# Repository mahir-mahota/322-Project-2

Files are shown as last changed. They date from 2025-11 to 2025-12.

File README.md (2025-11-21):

# 322-Project-2

1. Measure distances on the shaft and the forces from the gear
2. Find FrI and FrII (Fae is given) using moment equations
3. Find FaI and FaII, assuming axial load is not negligible
4. Find the effective loads PI and PII, P0I and P0II
5. Compute required C and C0 from L10 and fs
6. Compare with bearing C and C0 for feasability

For C:

1. The minimum shaft diameter is 54.6mm, and the maximum is 66mm - 55mm and 65mm are too close to the bounds
2. The housing width is 120mm so the bearing out diameter has to be smaller |red|
3. Without reducing housing thickness, the max bearing width T must be <30mm and we're contraining to >25mm

For D:

1. 70mm inner diameter is the smallest bearing that leads to an outer diameter of >= 150mm
2. The diameter of the pinion is 150mm so outer diameter of bearing has to be greater |red|

55-75 (55 is too small)
65-80 (80 has a 170 OD which is cutting it close)
65-85 (1mm step on shaft on either side)

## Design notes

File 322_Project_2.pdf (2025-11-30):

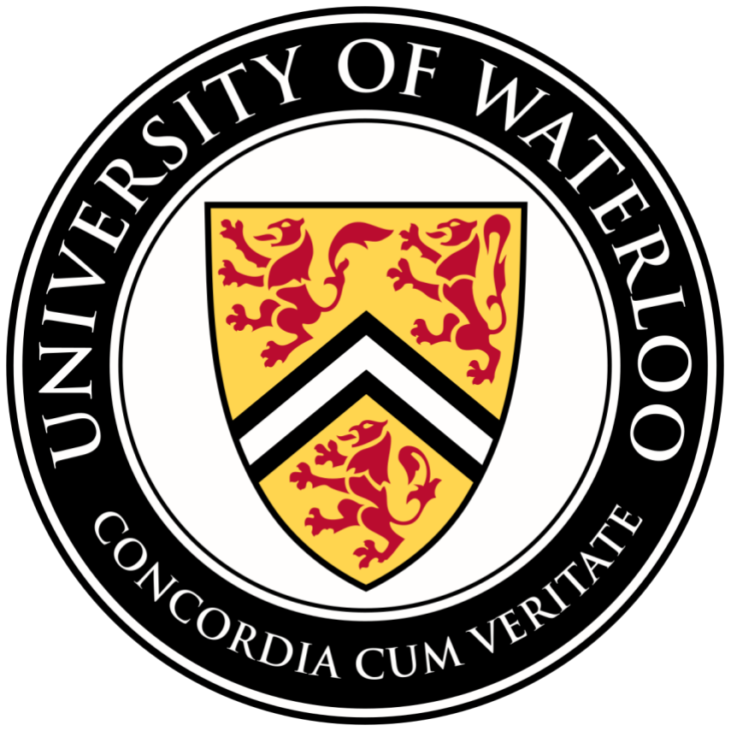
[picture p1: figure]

# MTE 322 PROJECT 2

# Mahir Mahota – 20991134 Vinesh Vivekanand – 21000784

## 28th October, 2025

### Motor selection

The input speed of the thrust motor on the pinion is ηP1 = 1,720rpm. Calculating the power required of the motor is:

Pout = 14,914N ∗ 10

m
s

= 149,140

Nm
s

= 149,140W = 149.14kW

Since there is no loss in power throughout the system, the output power is the same as the input power and countershaft power throughout the entire system, therefore:

Pout = Pcountersℎaft = Pin = 149.14kW

149.14kW ∗ 1.341 = 199.99674 ≈ 200ℎp
Therefore, selecting a motor with 200hp provides a suitable rating for this application. At the given power, a speed of 1800 rpm was selected based on the required 1,720 rpm.
Out of the options given, the cheapest Marathon E631A (https://www.emotorsdirect.ca/item/marathon-e631a) AC induction motor was chosen.

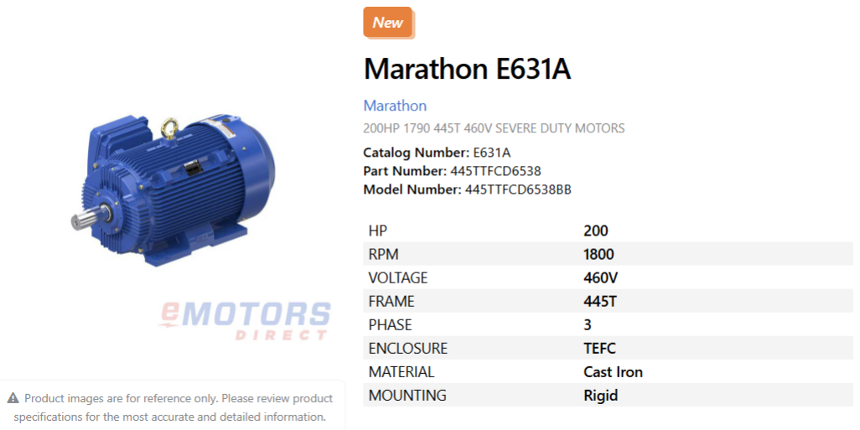
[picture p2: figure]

Figure 1 Selected motor for input shaft

### Bearing Selection

From Project 1:
WrG1 = WxP1 = 2.28 kN

WxG1 = WrP1 = 3.65 kN

WtG1 = WtP1 = 11.8kN
Below is the 3D FBD for the input shaft which is split into the x-z and y-z planes for two 2D FBDs:

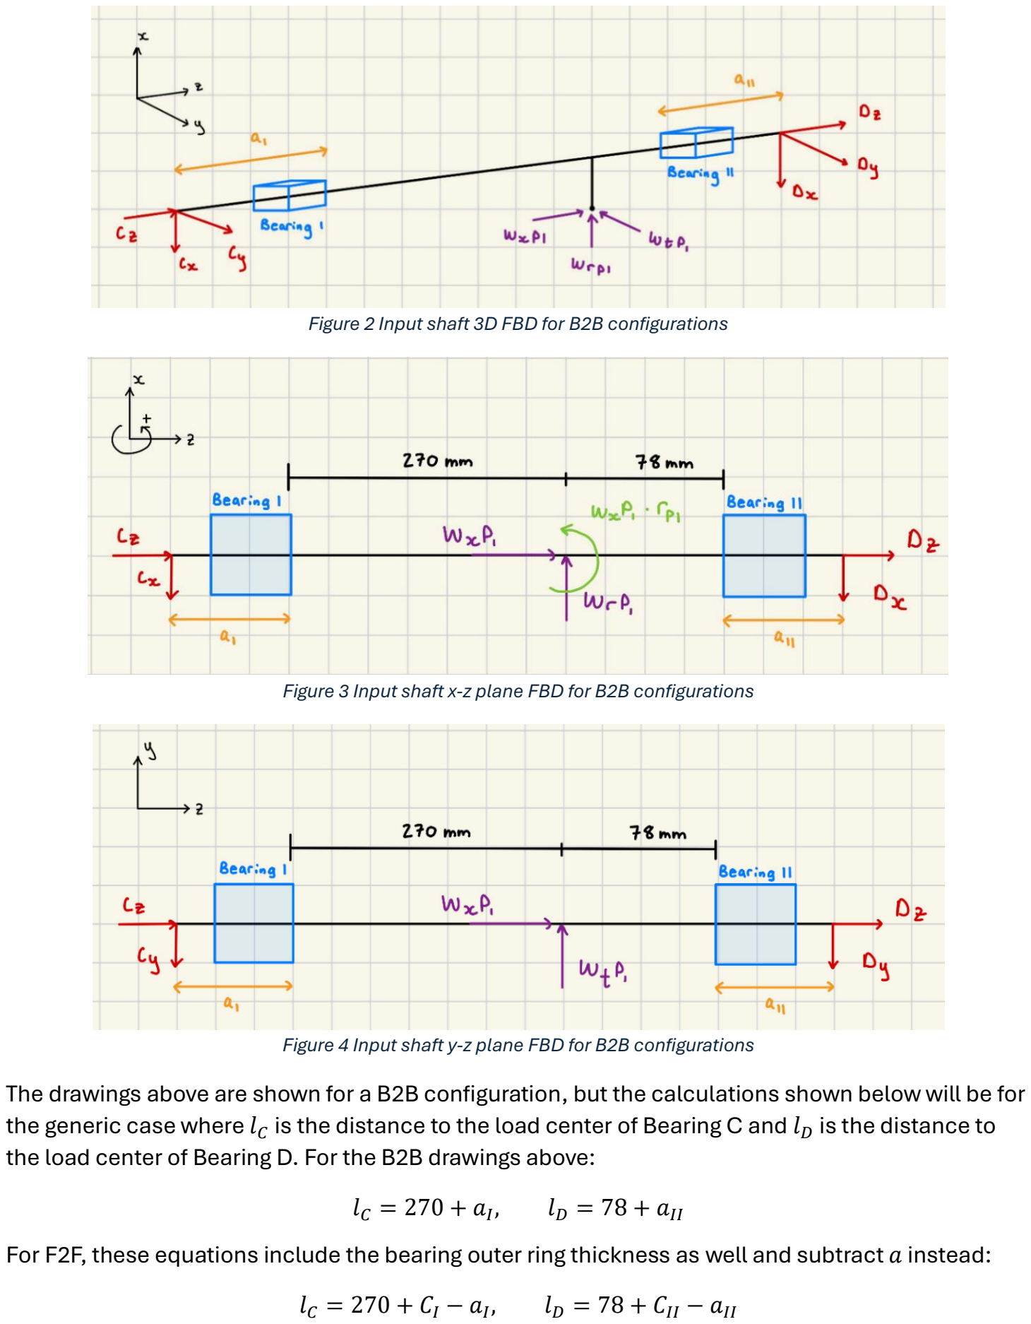
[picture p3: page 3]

Figure 2 Input shaft 3D FBD for B2B configurations

Figure 3 Input shaft x-z plane FBD for B2B configurations

Figure 4 Input shaft y-z plane FBD for B2B configurations
The drawings above are shown for a B2B configuration, but the calculations shown below will be for the generic case where lC is the distance to the load center of Bearing C and lD is the distance to the load center of Bearing D. For the B2B drawings above:

lC = 270 + aI

, lD = 78 + aII
For F2F, these equations include the bearing outer ring thickness as well and subtract a instead:

lC = 270 + CI − aI

, lD = 78 + CII − aII

Using the moment equations in the x-z plane

∑MD = 0 = −WrP1
(lD) + Cx

(lC + lD) + WxP1(rP1)

Cx =

WrP1

(lD) − WxP1(rP1)
(lC + lD)

=

3650(lD) − 2280(70)
(lC + lD)

∑MC = 0 = WrP1
(lC

) − Dx

(lC + lD) + WxP1(rP1)

Dx =

WrP1

(lC

) + WxP1(rP1)
(lC + lD)

=

3650(lC

) + 2280(70)
(lC + lD)
Using the moment equations in the y-z plane:

∑MD = 0 = −WtP1
(78 + aII) + Cy

(aI + 348 + aII)

Cy =

WtP1

(lD)
(lC + lD)

=

11800(lD)
(lC + lD)

∑MC = 0 = WtP1
(lC

) − Dy

(aII + 348 + aI

)

Dy =

WtP1

(lC

)
(lC + lD)

=

11800(lC

)
(lC + lD)
These can be combined to find the total radial force equation for each bearing:

FrI = Cr = √(
3650(lD) − 2280(70)
(lC + lD)

)

2
+ (
11800(lD)
(lC + lD)

)

2

FrII = Dr = √(
3650(lC

) + 2280(70)
(lC + lD)

)

2
+ (
11800(lC

)
(lC + lD)

)

2

Starting with these bearing radial forces, we can compute the resultant L10 and fs

for each bearing
to see if these parameters match the given requirements for the project. A Python program (Appendix A) was written to brute force all combinations of 55mm-80mm inner diameter bearings that fit the shaft diameter on either side. Both B2B and F2F configurations were tested separately and a total of 292 out of 5625 possible combinations were found that could support the pinion forces. Some extra size restrictions were added on top of the required L10 and fs specifications. These conditions were as follows:
1) The OD of Bearing D must be under the maximum housing width of 150mm
2) The C thickness of Bearing D must be less than the hole width of 40mm
3) The damin of Bearing D must be less than or equal to the shaft diameter of 86mm
4) The OD of Bearing C must be under the maximum housing width of 120mm
5) The C thickness of Bearing C must be less than the maximum hole width of 37mm
6) The damin of Bearing C must be less than or equal to the shaft diameter of 66mm

After these extra conditions, three F2F combinations were found that fit all the constraints:

Figure 5 Final working combinations of bearings given project requirements
Out of these three, the smallest possible bearings, given in row 1, were picked: HR32011XJ as Bearing C (I) and HR32313J as Bearing D (II). Example calculations from the program for this bearing combinations given below.
Calculating radial forces given the equivalent load centers of aI = 19.7mm and aII = 34mm:

FrI = √(
3650(78 + 39 − 34) − 2280(70) (83 + 267.8)

)

2
+ (

11800(78 + 39 − 34)
(83 + 267.8)

)

2
= 2828.417 N

FrII = √(
3650(270 + 17.5 − 19.7) + 2280(70) (83 + 267.8)

)

2
+ (
11800(270 + 17.5 − 19.7)
(83 + 267.8)

)

2
= 9594.743 N

For dynamic equivalent loads, we are assuming that the axial load is not negligible compared to e and therefore Y ≠ 0. Following from this, X = 0.4 and Y = Y1 for tapered roller bearings where Y1 is the axial load factor of each taper roller bearing in the catalogue.
Next, solve for FaI & FaII based on whichever F2F inequality is true:

Fae +

0.6
YI

FrI ≥

0.6

Y1II

FrII → FaII = Fae +

0.6

Y1I

FrI & FaI = 0

Fae +

0.6

Y1I

FrI <

0.6

Y1II

FrII → FaII = 0 & FaI =

0.6

Y1II

FrII − Fae

Since we chose bearings HR32011XJ and HR32313J, Y1I = 1.5 and Y1II = 1.7. WxP1 is also considered the external axial force and therefore is equal to Fae.

FaI = 0N

FaII = 3413.37N
Now that we have the axial and radial forces of both bearings (I and II), as well as the load factors, we can compute the dynamic equivalent loads, PI and PII.
We know that P = XFr + YFa only under the condition that Fa > 0. Therefore,

FaI = 0 → PI = FrII = 2828.42N

FaII > 0 → PII = 0.4(FrII) + 1.7(FaII) = 9640.63N

Next, using the values of Y0, we can calculate the static equivalent loads, P0I and P0II:

Y0I = 0.81

Y0II = 0.96

P0 = {

Fr

, | Fr > 0.5Fr + Y0Fa
0.5Fr + Y0Fa, Fr ≤ 0.5Fr + Y0Fa

0.5FrI + Y0IFaI = 0.5(2828.417 ) + 0.81(0) = 1414.2085 < FrI

| P0I = 2828.417

0.5FrII + Y0IIFaII = 0.5(9594.743) + 0.96(3413.37) = 8074.2067 < FrII

| P0II = 9594.743
Next, check if the L10 and fs

requirements are met for both bearings. Referring back to the NSK catalogue the basic load ratings for both bearings are as follows:

| C0I = 117,000 N
| C0II = 340,000 N
Safety factor requirements for Bearing C (I) and Bearing D (II):

fsI =

C0I

P0I

=

117000
2828.417 = 41.37

fsII =

C0II

P0II

=

340000
9594.743 = 35.44

fs < fsII < fsI

20 < 35.44 < 41.37
Therefore, both Bearings C and D abide by the requirements as the necessary safety factor against static failure for the selected bearings should be a minimum of 20.
Lifetime requirements for Bearing C (I) and Bearing D (II):

CI = 81,500 N

CII = 267,000 N

CI ≥ PI

(L10)

3
10

L10I ≤ [

CI
PI

]

10
3
= [

81500
2828.42N

]

10
3
= 73,346

CII ≥ PII(L10)

3
10

L10II ≤ [

CII

PII

]

10
3
= [

267,000
9640.63]

10
3
= 64,271

L10 < L10II < L10I

50,000 < 64,271 < 73,346
As the requirements state, both bearings must have a minimum L10 life equal to 50,000. According to the calculations shown above, bearings HR32011XJ as Bearing C (I) and HR32313J as Bearing D (II) both have a L10 life greater than 50,000.

### Modelling

To constrain Bearing C, steps were cut into the shaft and the housing. The shaft diameter was cut down from 66mm to 60mm to account for the bearing inner diameter. The hole in the housing was made larger from 80mm to 90mm to account for the outer diameter. This housing extruded cut was made 17.5mm deep, so that the inner face of the bearing sits flush with the housing wall.

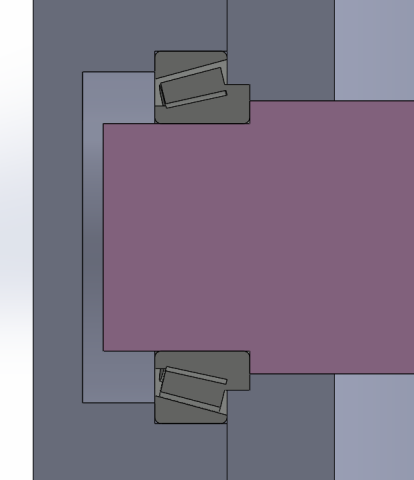
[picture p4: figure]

Figure 6 Bearing C installed into the housing
Since damin = 66mm, the shaft itself is enough to meet the abutment requirements for the inner ring. For the outer ring, the abutment diameter of Da = 80mm fits with the confines of Damin = 80mm and Damax = 81mm. Therefore, the bearing is properly constrained on load bearing corners. For Bearing D on the right side, the shaft was cut down from 86mm to 65mm to fit the inner diameter and create a constraining step in the shaft. Since the pinion diameter is approximately 150mm, the hole in the housing must be big enough to be able to fit the pinion and consequently also bigger than the 140mm outer diameter of the bearing. To support and constrain the bearing, the housing cover will be designed to fit between the housing opening and its outer ring. This cover will also provide a constraining step for the outer ring in much the same way the step in the housing was used with Bearing C. This bearing is also made to sit flush with the inner face of the housing.

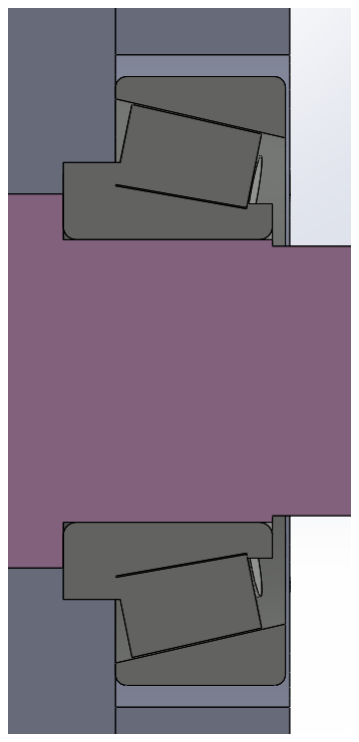
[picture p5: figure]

Figure 7 Bearing D fitted onto the shaft
Again, the shaft itself is enough to meet the inner ring abutment requirement of damin = 86mm and no external restraining rings are needed. The housing cover will be designed to meet the outer ring abutment requirements of being between Damin = 116mm and Damax = 128mm.
Before designing the housing cover, an appropriate lip seal must be selected to be placed after Bearing D on the shaft. Since the tolerancing of the lip seal should be different from the tolerancing of the bearing, another step must be cut here so that the lip seal sits on a different part of the shaft with a smaller diameter. The far end of the shaft, attached to the motor, has a diameter of 60mm and shouldn’t be cut down so a lip seal with a diameter of between 60mm and 65mm (ID of Bearing
D) can be picked. For this application, we went with the SKF 62x90x10 HMSA10 V seal and its placing can be seen in Figure 8 below:

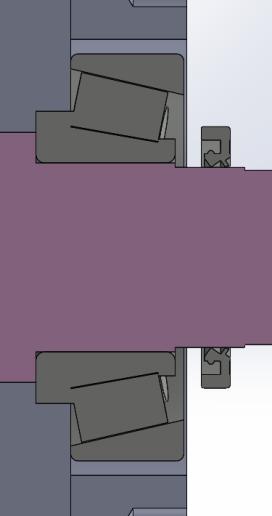
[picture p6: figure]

Figure 8 Lip seal fitted onto the shaft
Following this, the housing cover can be designed will all the bearing and lip seal constraints in mind. The 90mm OD of the lip seal should be able to fit snug within the cover, and the cover outer diameter should be big enough so that it’s able to be screwed into the existing holes in the housing. With regards to the bearing, Da was chosen to be 120mm thus fitting into the outer ring abutment requirements mentioned earlier. The cover was also designed to leave an Sa gap of 6mm, which is above the required Samin = 4mm. The final design is shown in Figure 9, after all sharp corners were chamfered by 5mm.

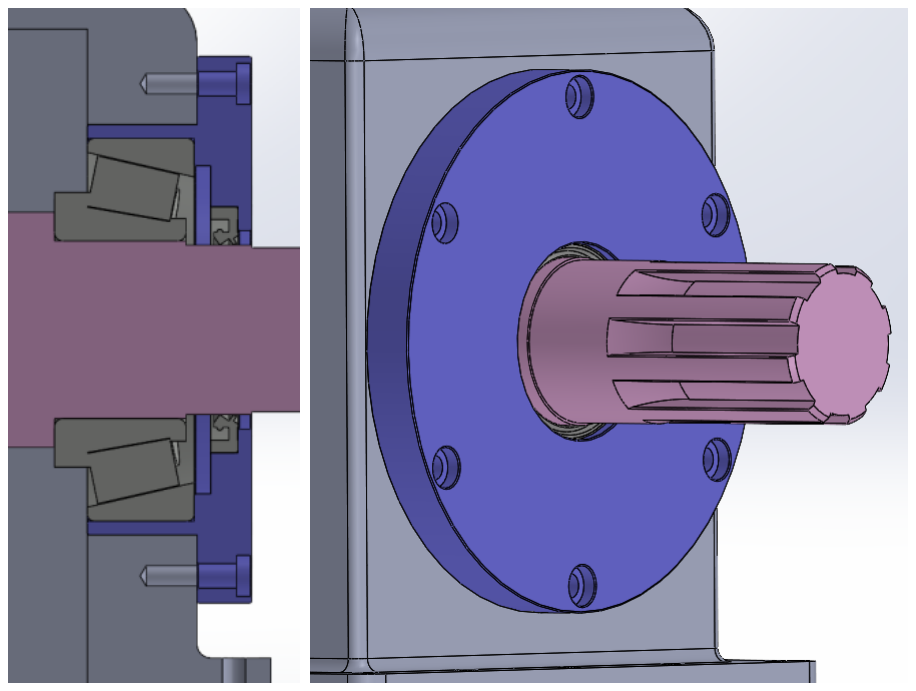
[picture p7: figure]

Figure 9 Final design for housing cover

### Tolerancing

Since the inner ring along with the inner ring load are rotating and the outer ring along with the outer ring load must be stationary, the inner ring is made to be tight fit while the outer ring is kept loose fit. To determine the tolerancing for Bearing C (I), the load conditions must be determined by finding the ratio between the capacity of the bearing and the actual load the bearing is experiencing.
For bearing HR 32011 XJ, CI = 81,500 N and PI = 2828.42 N

Load Condition =

PI
CI

=

2828.42
81500 = 0.0347 = 3.47%

This indicates that Bearing C is experiencing a “Light Load or Variable Load” (less than 6% of the Cr

)
as categorized in A84/85 of the NSK catalogue. Since the diameter of the shaft (66mm) is between 40-100mm, the suggested tolerancing is k6. The same calculation for Bearing D (II) is shown below:

For bearing HR 32313J, CII = 267,000 N and PII = 9640.63 N

Load Condition =

PII

CII

=

9640.63
267000 = 0.0361 = 3.61%

Similarly to Bearing C, Bearing C is experiencing a “Light Load or Variable Load” and as the shaft diameter (86mm) is again between 40-100mm the tolerancing used is k6 for this bearing as well. The housing tolerances must be determined next. Comparing the load conditions of the system with the conditions given in A85 of the NSK catalogue we recognize that both bearings used must have a rotating inner ring. In addition, both solid and split housing are useful for disassembly and consistent maintenance which would be vital for this marine propulsion system after a certain number of cycles have been reached. Both the bearings that were chosen should also be able to support loads of all kinds. Therefore, based on these categories we can ascertain the tolerances for the housing bores as H7. Thus, this results in both bearings having an H7/k6 tolerance.

According to SKF, the lip seal that chosen for our design has a nominal H8/h11tolerance. The tolerancing for all other new parts mated with the housing, such as the housing cover, follows a H7/g6 scheme. Lastly, if the step on the shaft and the step on the housing are too close together then the bearing won’t fit properly. Therefore, we will take the nominal tolerances and remove the most material condition for each step depth. This would mean that in the worst case, there is some extra space for the bearing but never not enough.

### Assembly

1) Since the pinion (P6) is to be placed in the middle of the shaft (P2) with a strong interference fit, it should be pushed first before the bearings (P8 and P9) and lip seal (P10). Force should be applied till it reaches the widest part of the shaft and contacts the narrow step.
2) The inner rings of the bearings (P8 and P9) should be tightly fit to the shaft (P2) next. Both bearings must be pushed onto the shaft with a sizeable force till they’re successfully made to be flush with their appropriate steps
a. Both bearings should be inserted with the side that has the inner ring sticking out made to be facing the pinion (P6) to ensure an F2F configuration
b. Bearing C (P8) is to be pushed in from the side farther from the pinion till its inner ring contacts the 66mm step
c. Bearing D (P9) is to be pushed in from the side closer behind the pinion till its inner ring contacts the 86mm step
3) Similarly, the lip seal (P10) should be pushed in tightly behind Bearing D (P9) till its inner face is at a distance of 9mm from the inner ring of the bearing
4) The shaft (P2) can then be pulled through the housing side cover (P7) till the cover contacts both the lip seal (P10) and Bearing D (P9). The cover should fit around the outer ring of Bearing D.
5) This full assembly can then be inserted into the housing (P1) from the 150mm hole in the side, with the Bearing C (P8) side going in first. The outer ring of Bearing C should contact the back of the housing, and the housing side cover (P7) should be flush with the side wall of the housing.
6) The housing cover (P7) should then be screwed into the housing (P1) using the counterbored and threaded holes on the cover and housing body respectively to fully secure the assembly.

### Appendix A:

1. import pandas as pd
2. from math import sqrt
3.
4. df = pd.read_csv('nsk.csv')
5. left_diameter = 66
6. right_diameter = 86
7. WxP1 = 2282
8. WrP1 = 3651
9. WtP1 = 11829
10. dI = 270
11. dII = 78
12. rP1 = 70
13. L10 = 50000
14. fs = 20
15. f2f = True
16.
17. # List to store results
18. results = []
19. count = 0
20.
21. for index_C, bC in df.iterrows():
22. for index_D, bD in df.iterrows():
23. if bC['d'] < left_diameter and bD['d'] < right_diameter and bC['damin'] <= left_diameter and bD['damin'] <= right_diameter:
24. CIr = bC['Cr']
25. CI0r = bC['C0r']
26. CIIr = bD['Cr']
27. CII0r = bD['C0r']
28.
29. if f2f == True:
30. lC = dI - bC['a'] + bC['C']
31. lD = dII - bD['a'] + bD['C']
32. else:
33. lC = dI + bC['a']
34. lD = dII + bD['a']
35.
36. Cx = ((WrP1*lD)-(WxP1*rP1)) / (lC+lD)
37. Cy = (WtP1*lD) / (lC+lD)
38. Dx = ((WrP1*lC)+(WxP1*rP1)) / (lC+lD)
39. Dy = (WtP1*(lC)) / (lC+lD)
40.
41. FrI = sqrt(Cx*Cx + Cy*Cy)
42. FrII = sqrt(Dx*Dx + Dy*Dy) 43.
44. FaI = 0
45. FaII = 0
46. if f2f == True:
47. if ((WxP1 + (0.6 * FrI / bC['Y1'])) >= (0.6 * FrII / bD['Y1'])):
48. FaII = WxP1 + (0.6 * FrI / bC['Y1'])
49. else:
50. FaI = (0.6 * FrII / bD['Y1']) - WxP1
51. else:
52. if ((WxP1 + (0.6 * FrII / bD['Y1'])) >= (0.6 * FrI / bC['Y1'])):
53. FaI = WxP1 + (0.6 * FrII / bD['Y1'])
54. else:
55. FaII = (0.6 * FrI / bC['Y1']) - WxP1
56.
57. PI = (0.4*FrI + bC['Y1']*FaI) if FaI > 0 else FrI
58. PII = (0.4*FrII + bD['Y1']*FaII) if FaII > 0 else FrII 59.
60. P0I = 0.5*FrI + bC['Y0']*FaI
61. P0II = 0.5*FrII + bD['Y0']*FaII

62. if FrI > P0I:
63. P0I = FrI
64. if FrII > P0II:
65. P0II = FrII
66.
67. CIreq = PI * (L10 ** (3/10))
68. CI0req = fs * P0I
69. CIIreq = PII * (L10 ** (3/10))
70. CII0req = fs * P0II
71.
72. if CIreq < CIr and CI0req < CI0r and CIIreq < CIIr and CII0req < CII0r:
73. print(bC['Bearing'], bD['Bearing'])
74. # Store all data in a dictionary
75. result_row = {
76. 'Bearing_I': bC['Bearing'],
77. 'ID_I' : bC['d'],
78. 'OD_I' : bC['D'],
79. 'T_I' : bC['T'],
80. 'C_I' : bC['C'],
81. 'da_min_I' : bC['damin'],
82. 'Bearing_II': bD['Bearing'],
83. 'ID_II' : bD['d'],
84. 'OD_II' : bD['D'],
85. 'T_II' : bD['T'],
86. 'C_II' : bD['C'],
87. 'da_min_II' : bD['damin'],
88. 'Fr_I' : FrI,
89. 'Fr_II' : FrII,
90. 'Fa_I' : FaI,
91. 'Fa_II' : FaII,
92. 'P_I' : PI,
93. 'P_II' : PII,
94. 'P0_I' : P0I,
95. 'P0_II' : P0II,
96. }
97. results.append(result_row)
98. count += 1
99.
100. print(f"\n{count} combinations checked")
101. if results:
102. results_df = pd.DataFrame(results)
103. results_df.to_csv('bearing_results.csv', index=False)
104. print(f"Saved {len(results)} results to bearing_results.csv")
105. else:
106. print("No results found matching the criteria.")
107.
108.

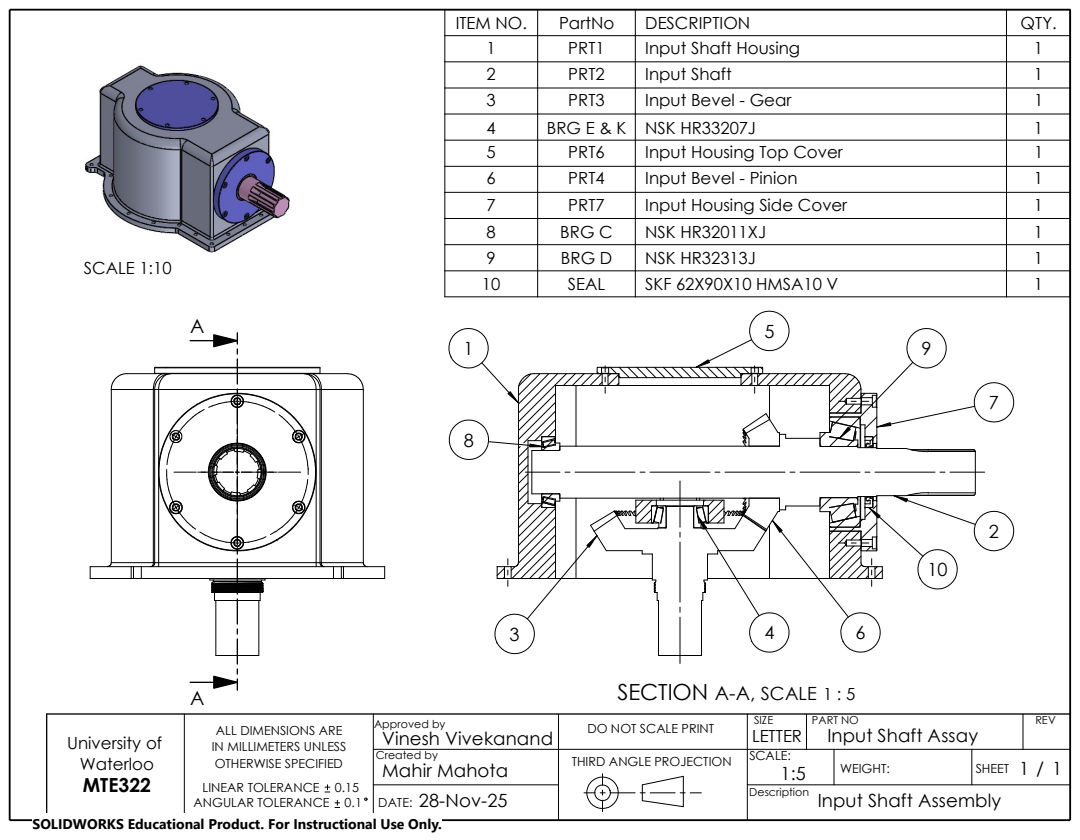
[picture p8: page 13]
Description; DATE:; 28-Nov-25; Input Shaft Assembly; SCALE 1:10; SCALE 1 : 5; SECTION A-A,

ITEM NO. | PartNo | DESCRIPTION | QTY.
1 | PRT1 | Input Shaft Housing | 1
2 | PRT2 | Input Shaft | 1
3 | PRT3 | Input Bevel - Gear | 1
4 | BRG E & K | NSK HR33207J | 1
5 | PRT6 | Input Housing Top Cover | 1
6 | PRT4 | Input Bevel - Pinion | 1
7 | PRT7 | Input Housing Side Cover | 1
8 | BRG C | NSK HR32011XJ | 1
9 | BRG D | NSK HR32313J | 1
10 | SEAL | SKF 62X90X10 HMSA10 V | 1

University of Waterloo MTE322 | ALL DIMENSIONS ARE IN MILLIMETERS UNLESS OTHERWISE SPECIFIED LINEAR TOLERANCE 0.15 ANGULAR TOLERANCE 0.1 | Approved by Vinesh Vivekanand | DO NOT SCALE PRINT | SIZE LETTER | PART NO Input Shaft Assay | REV
Created by Mahir Mahota | THIRD ANGLE PROJECTION | SCALE: 1:5 | WEIGHT: | 1 1 / SHEET

SOLIDWORKS Educational Product. For Instructional Use Only.

8 | 7 6 | 5 | 4 | 3 | 2 | 1

E E

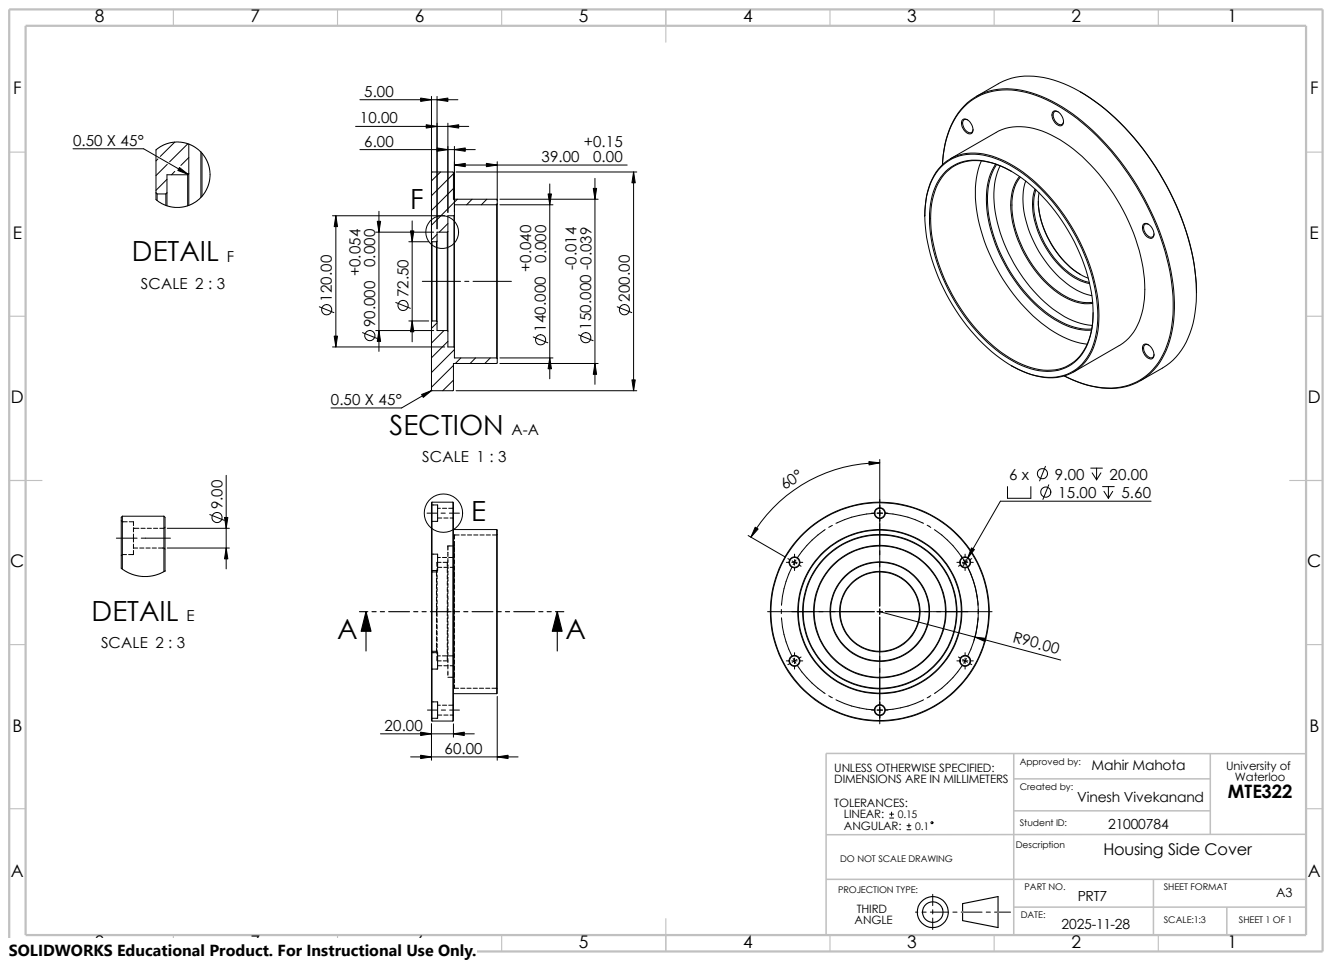
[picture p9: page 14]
Vinesh Vivekanand; MTE322; Approved by:; Created by:; Student ID:; Mahir Mahota; Waterloo; ANGLE; University of; THIRD; SECTION A-A; SCALE; DETAIL F; SCALE 2 : 3; DETAIL E

UNLESS OTHERWISE SPECIFIED:
DIMENSIONS ARE IN MILLIMETERS
TOLERANCES:
LINEAR: 0.15
ANGULAR:

DO NOT SCALE DRAWING | Description Housing Side Cover

PROJECTION TYPE: | PART NO. PRT7 | SHEET FORMAT A3

DATE: 2025-11-28 | SCALE:1:3 | SHEET 1 OF 1

SOLIDWORKS Educational Product. For Instructional Use Only.

3

6 4

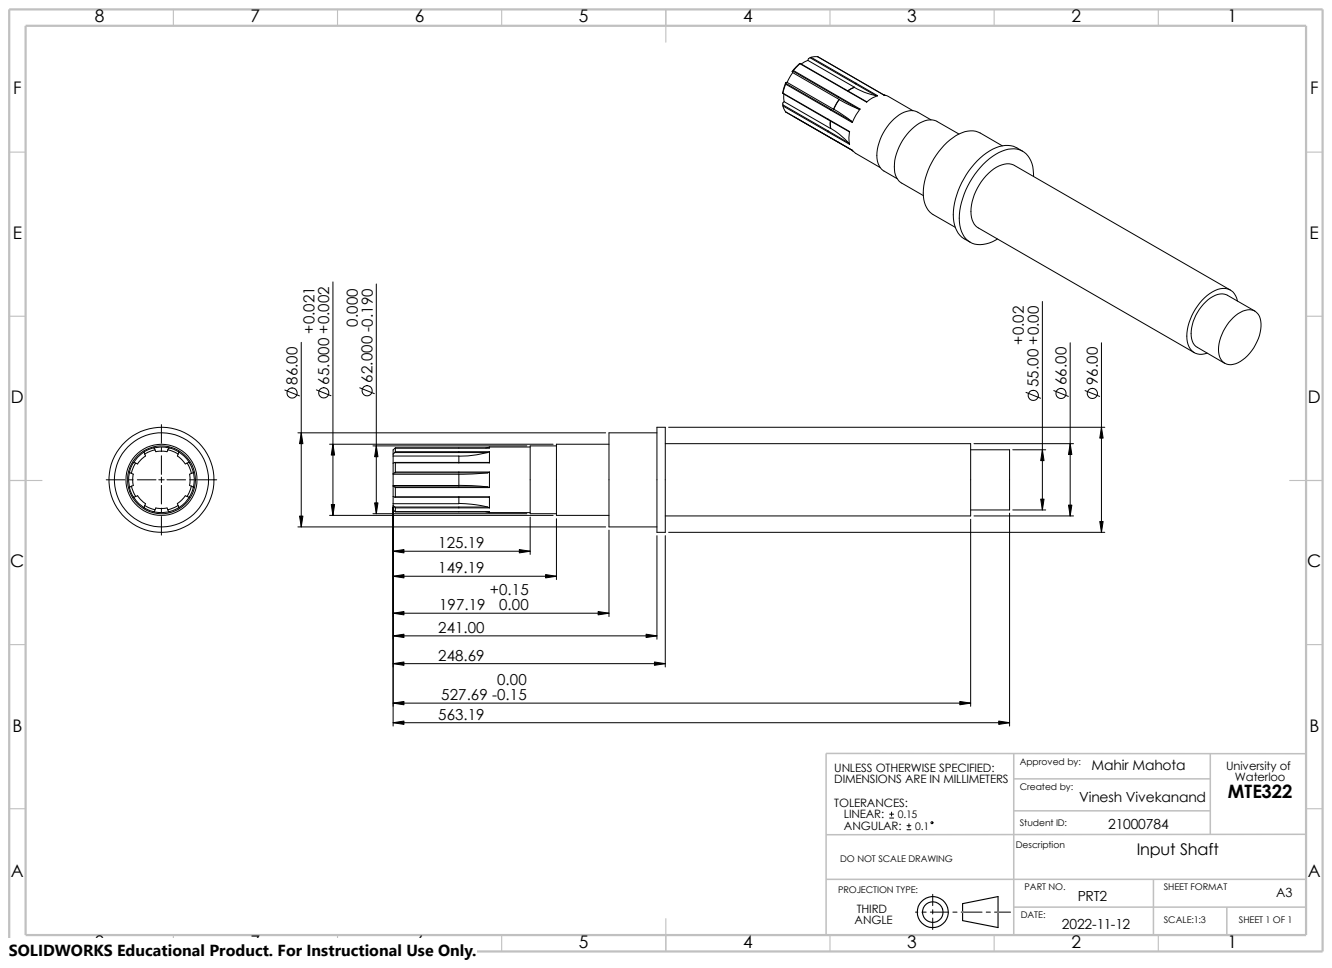
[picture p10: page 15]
MTE322; Approved by:; Created by:; Student ID:; Mahir Mahota; Vinesh Vivekanand; Waterloo; ANGLE; University of; THIRD

UNLESS OTHERWISE SPECIFIED:
DIMENSIONS ARE IN MILLIMETERS
TOLERANCES:
LINEAR: 0.15
ANGULAR:

DO NOT SCALE DRAWING | Description Input Shaft

PROJECTION TYPE: | PART NO. PRT2 | SHEET FORMAT A3

DATE: 2022-11-12 | SCALE:1:3 | SHEET 1 OF 1

SOLIDWORKS Educational Product. For Instructional Use Only.

3

6 4

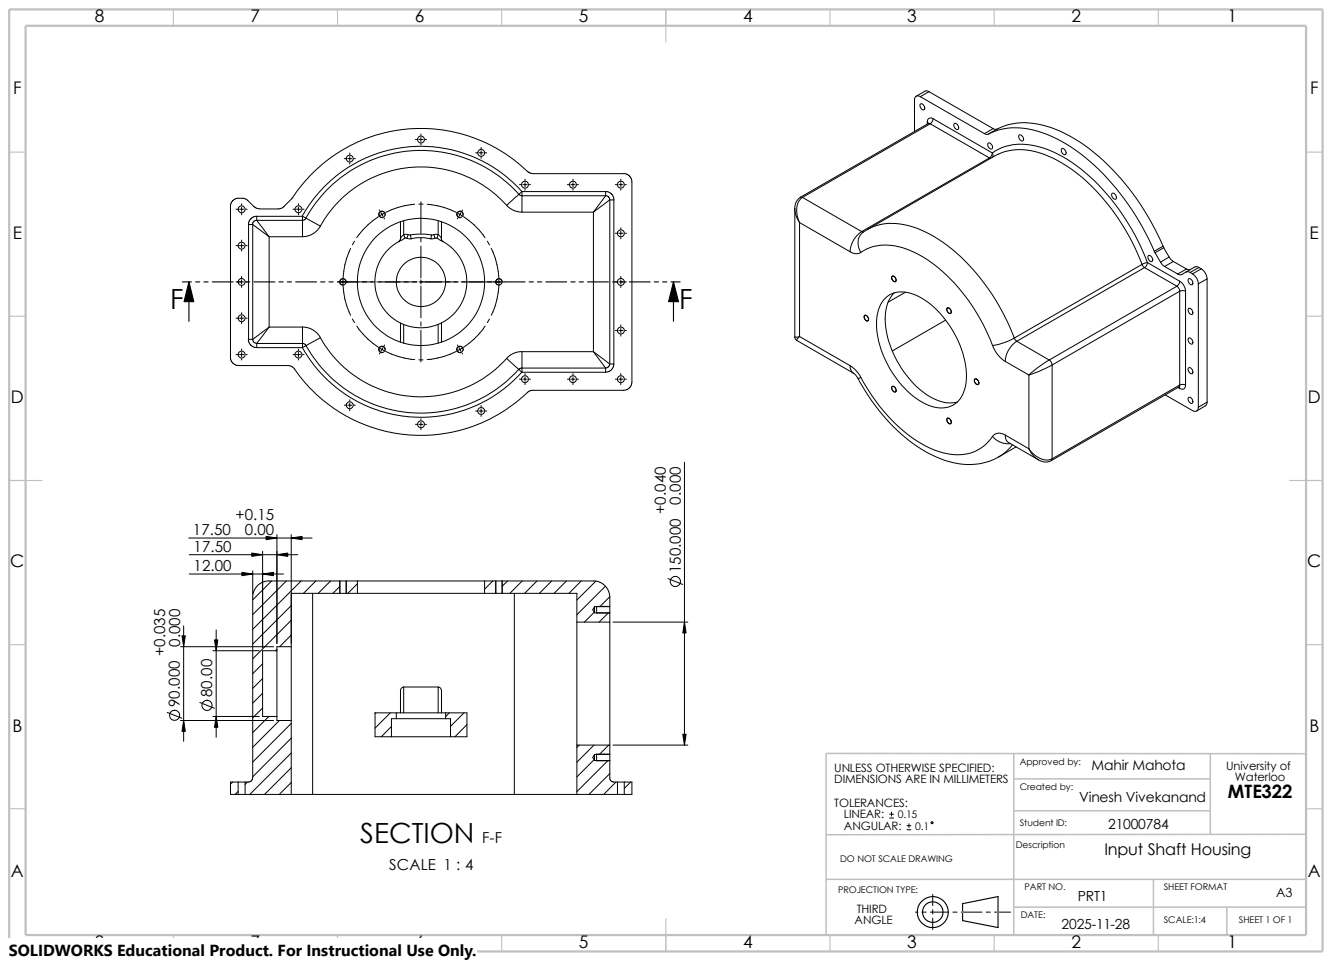
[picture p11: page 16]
MTE322; Approved by:; Created by:; Student ID:; Mahir Mahota; Vinesh Vivekanand; Waterloo; ANGLE; University of; THIRD; SECTION F-F; SCALE 1 : 4 ⁸⁰.00 0.035 0.000 90.000

UNLESS OTHERWISE SPECIFIED:
DIMENSIONS ARE IN MILLIMETERS
TOLERANCES:
LINEAR: 0.15
ANGULAR:

DO NOT SCALE DRAWING | Description Input Shaft Housing

PROJECTION TYPE: | PART NO. PRT1 | SHEET FORMAT A3

DATE: 2025-11-28 | SCALE:1:4 | SHEET 1 OF 1

SOLIDWORKS Educational Product. For Instructional Use Only.

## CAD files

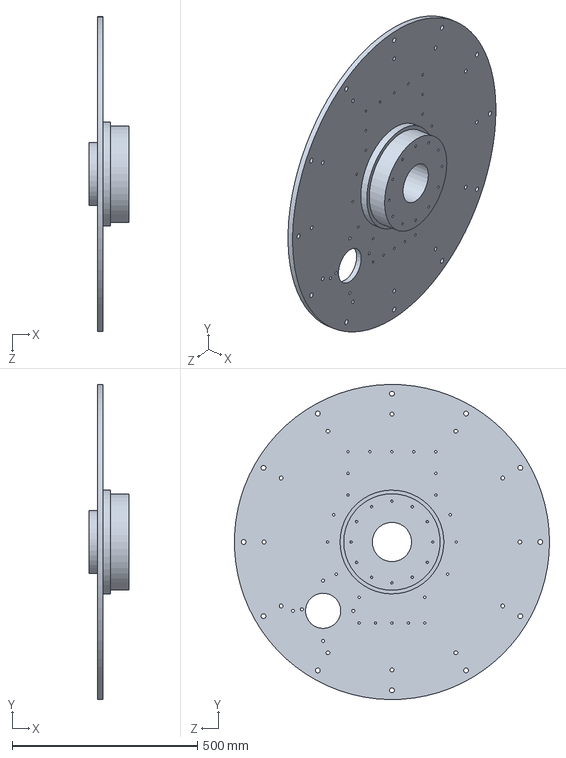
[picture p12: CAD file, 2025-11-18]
SOLIDWORKS_P1/Housing_main_cover.SLDPRT
108.0 x 849.8 x 849.7 mm

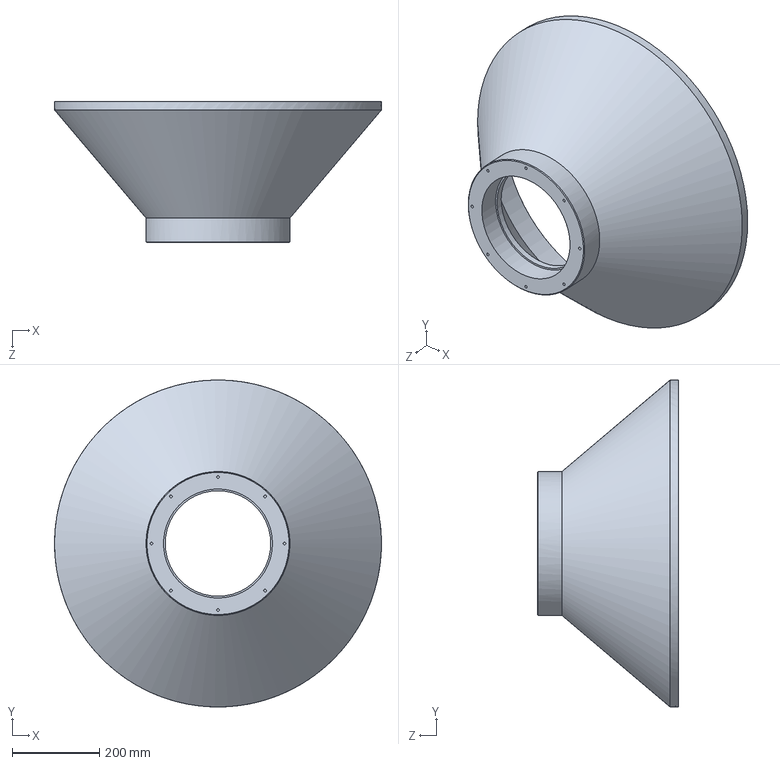
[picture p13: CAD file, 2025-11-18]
SOLIDWORKS_P1/Housing_well.SLDPRT
750.0 x 749.8 x 324.5 mm

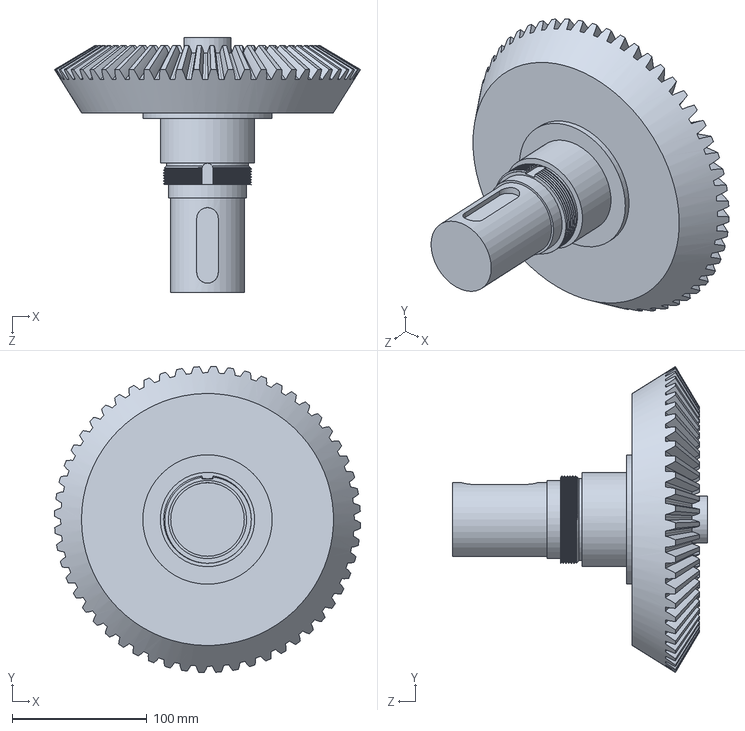
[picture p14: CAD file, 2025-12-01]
SOLIDWORKS_P2/Input_shaft_assay_4_Proj2/Input_bevel_gear.SLDPRT
227.0 x 227.0 x 189.3 mm

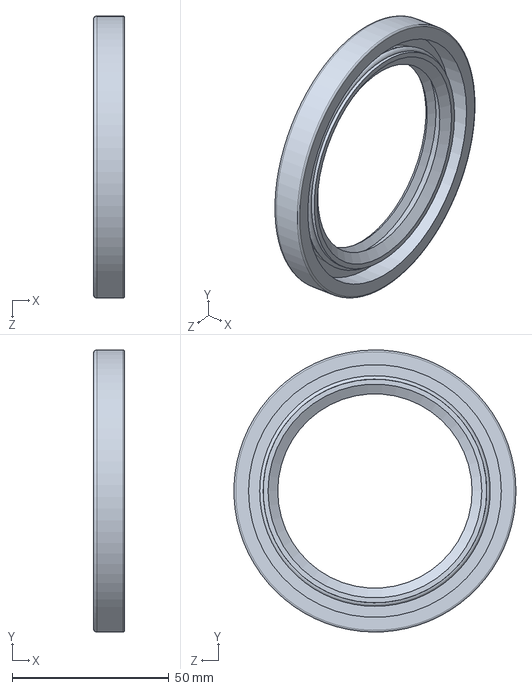
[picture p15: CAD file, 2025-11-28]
SOLIDWORKS_P2/Input_shaft_assay_4_Proj2/Lip Seal/SKF_62X90X10 HMSA10 V.sldprt
10.0 x 90.0 x 90.0 mm

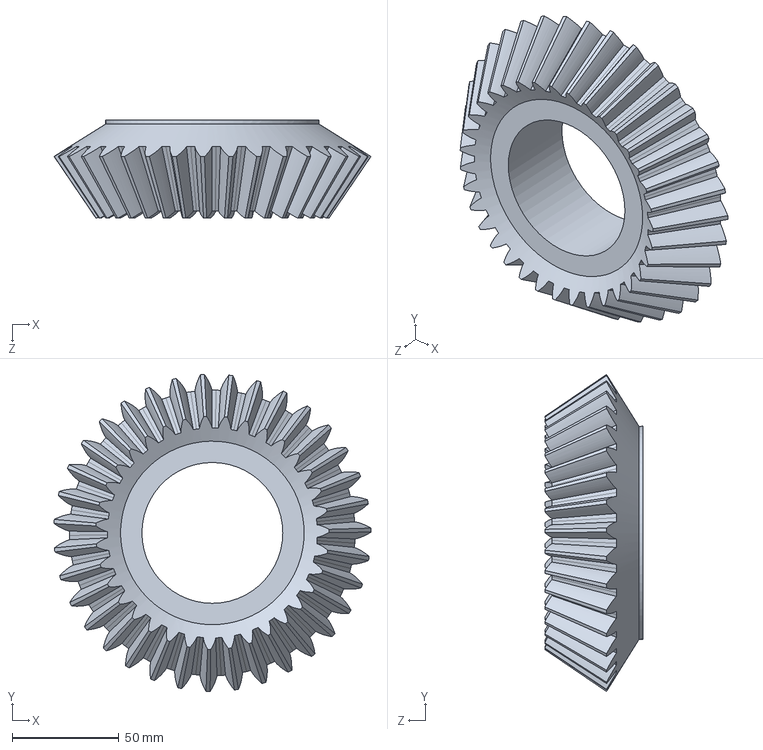
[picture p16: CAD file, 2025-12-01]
SOLIDWORKS_P2/Input_shaft_assay_4_Proj2/Input_bevel_pinion.SLDPRT
148.6 x 148.6 x 46.2 mm

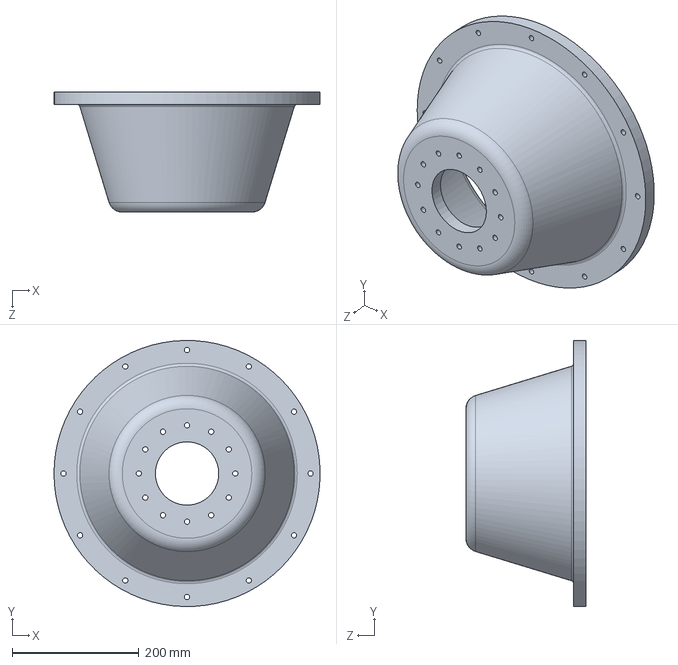
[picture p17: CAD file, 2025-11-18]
SOLIDWORKS_P1/Housing_azi_gear.SLDPRT
419.8 x 419.9 x 190.0 mm

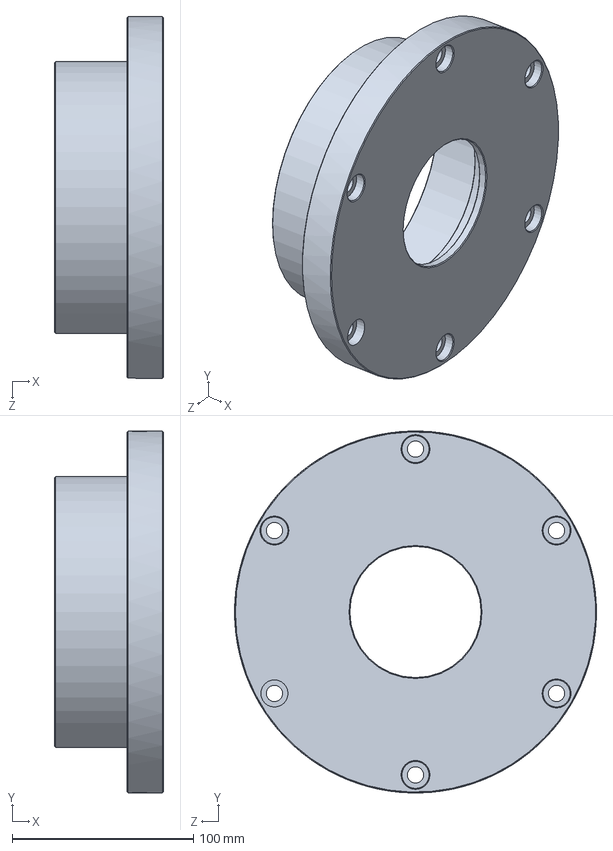
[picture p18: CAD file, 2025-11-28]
SOLIDWORKS_P2/Input_shaft_assay_4_Proj2/Housing_cover.SLDPRT
60.0 x 199.9 x 200.0 mm

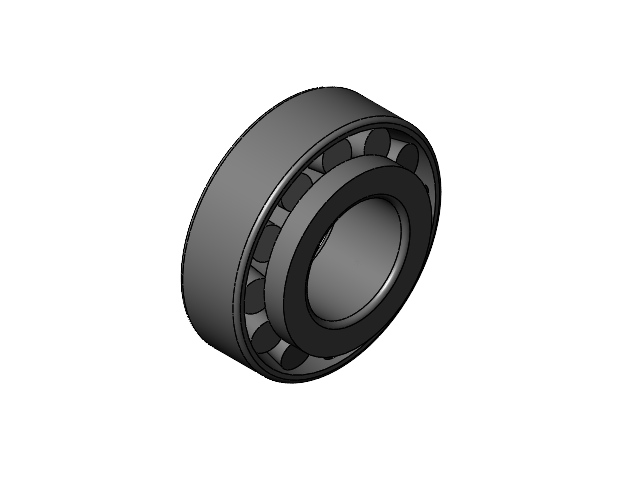
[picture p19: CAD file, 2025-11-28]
SOLIDWORKS_P2/Input_shaft_assay_4_Proj2/Bearing D/NSK_HR32313J.sldasm
HR32313J Inner ring
HR32313J Outer ring

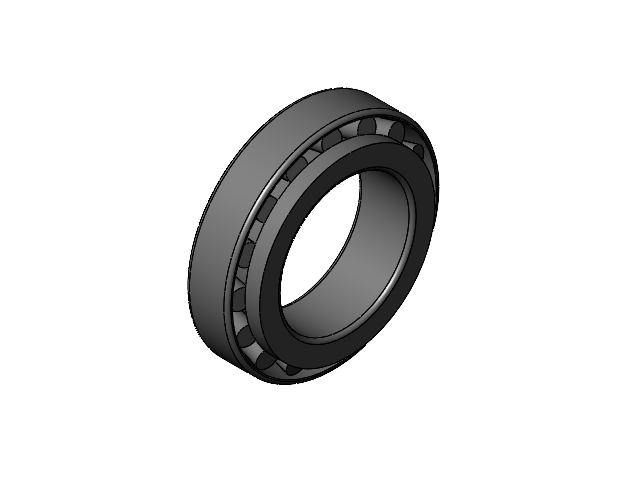
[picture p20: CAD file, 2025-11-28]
SOLIDWORKS_P2/Input_shaft_assay_4_Proj2/Bearing_C/NSK_HR32011XJ.sldasm
HR32011XJ Inner ring
HR32011XJ Outer ring

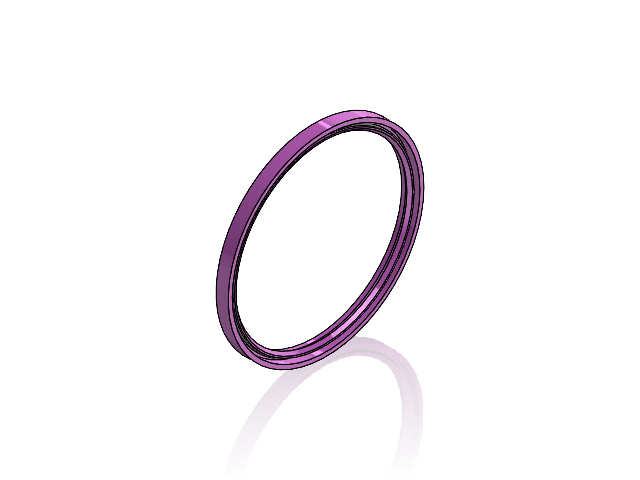
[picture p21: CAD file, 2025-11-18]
SOLIDWORKS_P1/SKF_210X240X15 HMS5 RG.SLDASM
SKF_210X240X15 HMS5 RG
SKF_210X240X15 HMS5 RG Spring

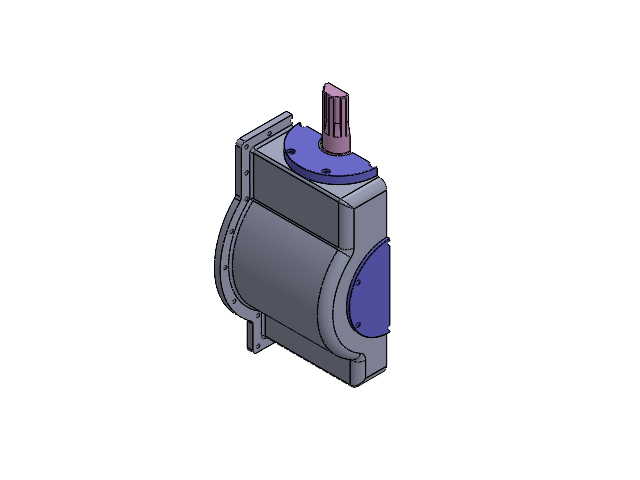
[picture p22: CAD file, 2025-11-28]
SOLIDWORKS_P2/Input_shaft_assay_4_Proj2/Input_shaft_assay_4_Proj2.SLDASM
Housing_input
Input_shaft
Input_bevel_gear
HR33207J Inner ring
HR33207J Outer ring
Housing_input_cover
Input_bevel_pinion
Housing_cover
HR32011XJ Inner ring
HR32011XJ Outer ring
HR32313J Inner ring
HR32313J Outer ring
SKF_62X90X10 HMSA10 V

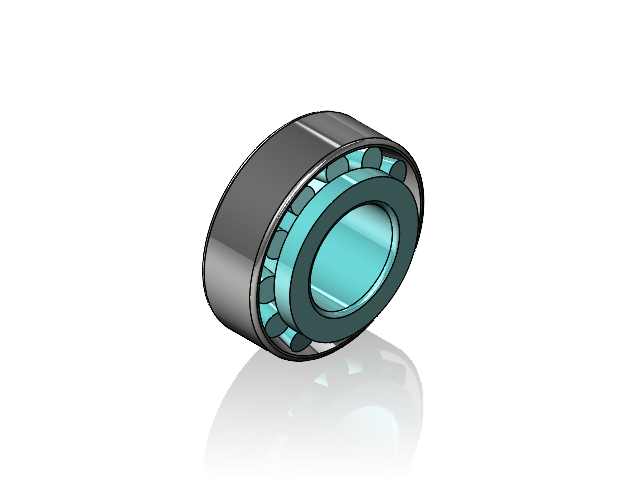
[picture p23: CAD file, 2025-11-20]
SOLIDWORKS_P2/Input_shaft_assay_4_Proj2/Bearing_EL_NSK_HR33207J.SLDASM
HR33207J Inner ring
HR33207J Outer ring

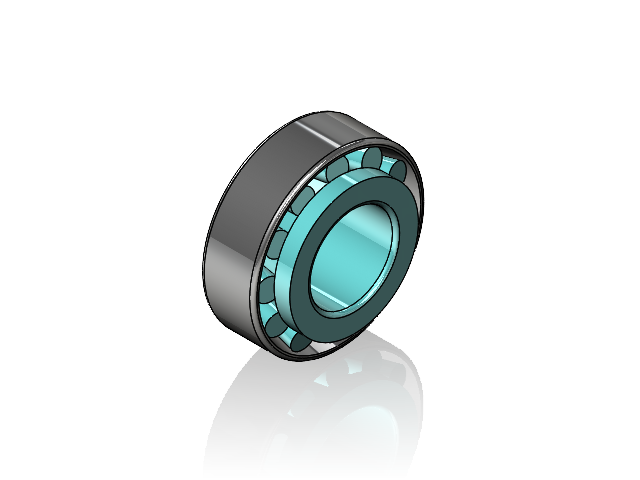
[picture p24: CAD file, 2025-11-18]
SOLIDWORKS_P1/Bearing_EL_NSK_HR33207J.SLDASM
HR33207J Inner ring
HR33207J Outer ring

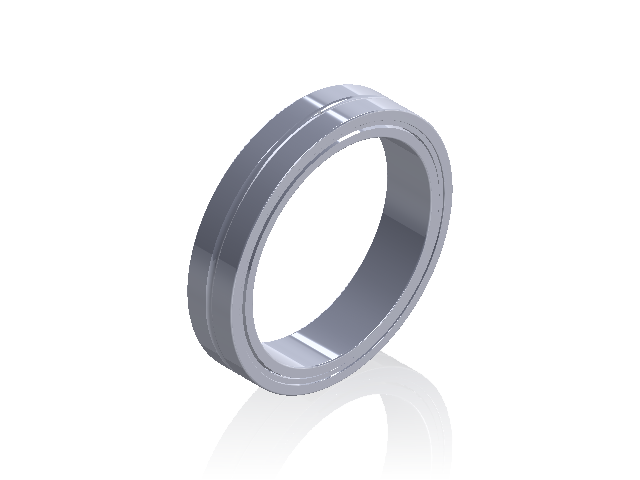
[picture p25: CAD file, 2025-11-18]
SOLIDWORKS_P1/Bearing_J_SKF_NA4840_2.SLDASM
skf_bearing_na_4840_2_01
skf_bearing_na_4840_2_02
skf_bearing_na_4840_2_03
skf_bearing_na_4840_2_04

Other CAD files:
SOLIDWORKS_P1/Bearing_GK_NSK_HR33114J.SLDASM
SOLIDWORKS_P1/Bearing_H_61952_ma_2.SLDASM
SOLIDWORKS_P1/Assem Quill Handle.SLDASM
SOLIDWORKS_P1/azimuth_motor.SLDASM
SOLIDWORKS_P1/3408A220_BALL-NOSE SPRING PLUNGER W SS BALL.SLDPRT
SOLIDWORKS_P1/91595A399_METRIC ALLOY STEEL DOWEL PIN.SLDPRT
SOLIDWORKS_P1/96200010_back.SLDPRT
SOLIDWORKS_P1/96200010_connect.SLDPRT
SOLIDWORKS_P1/96200010_front_wo_shaft.SLDPRT
SOLIDWORKS_P1/96717A696_Rounded Machine Key.SLDPRT
SOLIDWORKS_P1/Azi_gear.SLDPRT
SOLIDWORKS_P1/Azi_pinion.SLDPRT
SOLIDWORKS_P1/Azi_seal_housing1.SLDPRT
SOLIDWORKS_P1/Azi_seal_housing2.SLDPRT
SOLIDWORKS_P1/Azi_seal_housing3.SLDPRT
SOLIDWORKS_P1/Blade.SLDPRT
SOLIDWORKS_P1/Blade_clamp.SLDPRT
SOLIDWORKS_P1/Brg_H_inner_cover.SLDPRT
SOLIDWORKS_P1/Brg_K_outer_cover1.SLDPRT
SOLIDWORKS_P1/Brg_K_outer_cover2.SLDPRT
SOLIDWORKS_P1/Counter_shaft.SLDPRT
SOLIDWORKS_P1/Coupler.SLDPRT
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

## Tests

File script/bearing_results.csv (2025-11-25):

Bearing_I | ID_I | OD_I | T_I | C_I | da_min_I | Bearing_II | ID_II | OD_II | T_II | C_II | da_min_II | Fr_I | Fr_II | Fa_I | Fa_II | P_I | P_II | P0_I | P0_II
HR 32011 XJ | 55 | 90 | 23.0 | 17.5 | 66 | HR 32313 J | 65 | 140 | 51.0 | 39.0 | 86 | 2828.4167088012246 | 9594.74339585649 | 0.0 | 3413.3666835204895 | 2828.4167088012246 | 9640.620720327428 | 2828.4167088012246 | 9594.74339585649
HR 33011 J | 55 | 90 | 27.0 | 21.0 | 66 | HR 32313 J | 65 | 140 | 51.0 | 39.0 | 86 | 2796.529259998505 | 9625.998497182252 | 1115.4112342996186 | 0.0 | 3237.893049168678 | 9625.998497182252 | 2796.529259998505 | 9625.998497182252
HR 33111 J | 55 | 95 | 30.0 | 23.0 | 66 | HR 32313 J | 65 | 140 | 51.0 | 39.0 | 86 | 2806.019743912527 | 9616.695781358103 | 1112.127922832272 | 0.0 | 2901.812574096646 | 9616.695781358103 | 2806.019743912527 | 9616.695781358103

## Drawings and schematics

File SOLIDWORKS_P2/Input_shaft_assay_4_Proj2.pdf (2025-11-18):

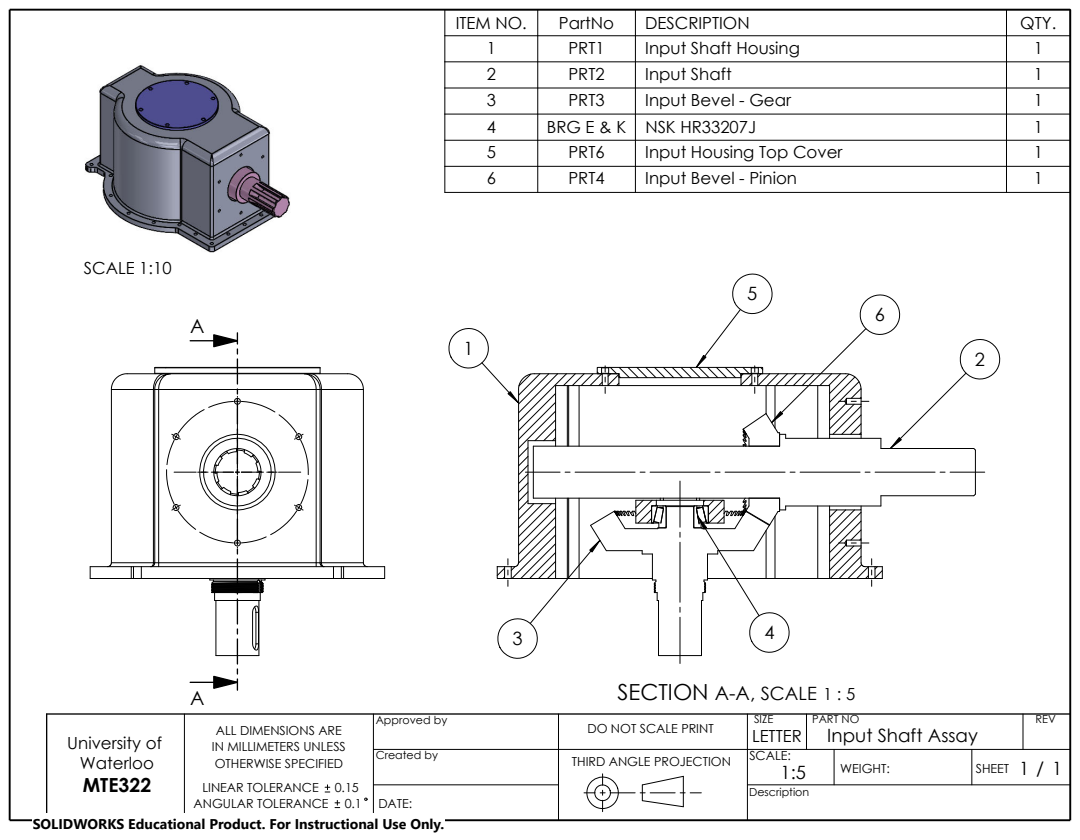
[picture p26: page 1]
Description 0.15; / 1 OTHERWISE SPECIFIED; DATE:; SCALE 1 : 5; SECTION A-A,; SCALE 1:10

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

University of Waterloo MTE322 | ALL DIMENSIONS ARE IN MILLIMETERS UNLESS LINEAR TOLERANCE ANGULAR TOLERANCE 0.1 | Approved by | DO NOT SCALE PRINT | SIZE LETTER | PART NO Input Shaft Assay | REV
Created by | THIRD ANGLE PROJECTION | SCALE: 1:5 | WEIGHT: | 1 SHEET

SOLIDWORKS Educational Product. For Instructional Use Only.

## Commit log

2025-11-18 adding files
    [3408A220_BALL-NOSE SPRING PLUNGER W SS BALL.SLDPRT, 91595A399_METRIC ALLOY STEEL DOWEL PIN.SLDPRT, 96200010_back.SLDPRT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]
2025-11-20 adding bearing C
    [Bearing_EL_NSK_HR33207J.SLDASM, HR33207J Inner ring.sldprt, HR33207J Outer ring.sldprt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]
2025-11-20 adding bearing D
    [HR30312DJ Inner ring.sldprt, HR30312DJ Outer ring.sldprt, HR32314J Inner ring.sldprt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]
2025-11-21 adding search script
    [bearing_results.csv, nsk.csv]
2025-11-21 changing bearings
    [HR30312DJ Inner ring.sldprt, HR30312DJ Outer ring.sldprt, HR31312J Inner ring.sldprt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]
2025-11-25 updating for f2f
    [Housing_cover.SLDPRT, Input_shaft.SLDPRT, Input_shaft_assay_4_Proj2.SLDASM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]
2025-11-25 added damin restriction
    [HR31312J Inner ring.sldprt, HR31312J Outer ring.sldprt, Housing_cover.SLDPRT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]
2025-11-25 adding f2f combination
    [HR32011XJ Inner ring.sldprt, HR32011XJ Outer ring.sldprt, HR32313J Inner ring.sldprt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]
2025-11-25 fitting bearings
    [HR32011XJ Inner ring.sldprt, HR32011XJ Outer ring.sldprt, HR32313J Inner ring.sldprt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]
2025-11-27 finished cad
    [Housing_cover.SLDPRT, Housing_input.SLDPRT, Input_shaft.SLDPRT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]
2025-11-28 starting drawings
    [Housing_input.SLDPRT, Input_shaft.SLDDRW, Input_shaft_assay_4_Proj2.SLDASM]
2025-11-28 changing lip seal
    [Housing_cover.SLDPRT, Input_shaft.SLDPRT, Input_shaft_assay_4_Proj2.SLDASM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]
2025-11-28 assembly drawing
    [Housing_cover.SLDPRT, Input_shaft_assay_4_Proj2.SLDASM, Input_shaft_assay_4_Proj2.SLDDRW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]
2025-11-29 updated aseembly legend
    [Input_shaft_assay_4_Proj2.SLDDRW]
2025-11-30 finished drawings
    [Housing_cover.SLDDRW, Housing_input.SLDDRW, Input_shaft.SLDDRW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]
2025-12-01 pazk and go
    [Input_bevel_gear.SLDPRT, Input_bevel_pinion.SLDPRT]
